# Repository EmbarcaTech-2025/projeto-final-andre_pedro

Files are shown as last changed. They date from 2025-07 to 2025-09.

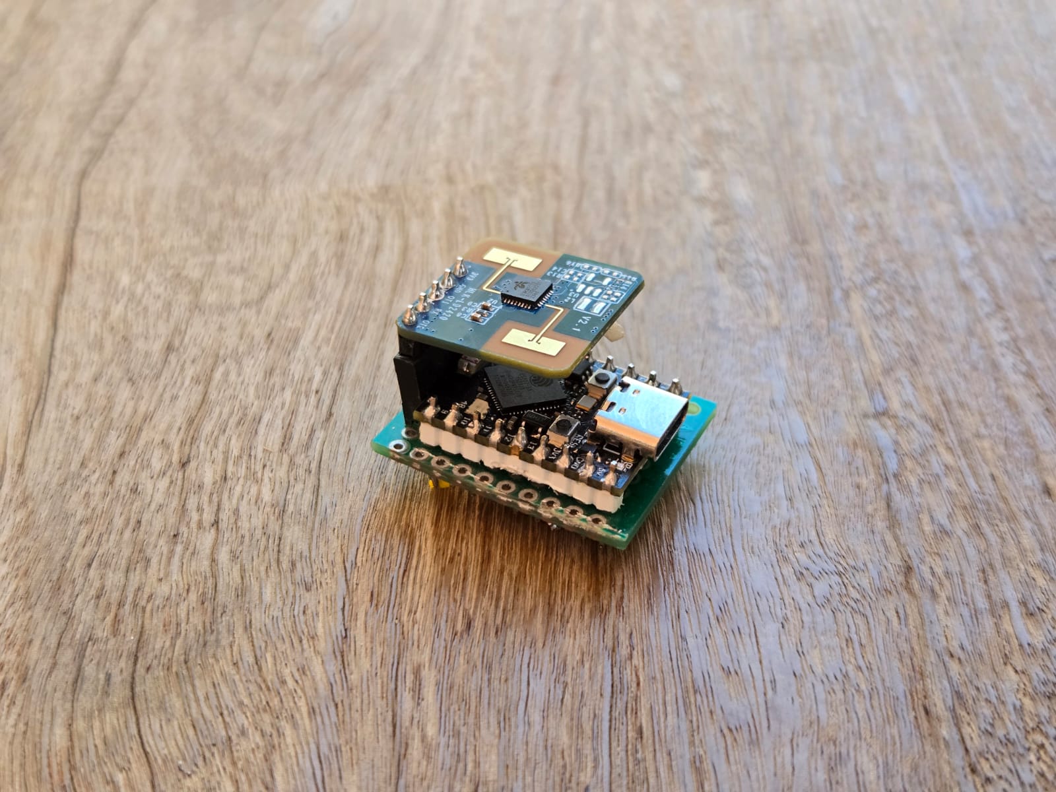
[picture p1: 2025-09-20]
etapa_4/imagens_e_videos/sonofree_mini_montagem.jpeg

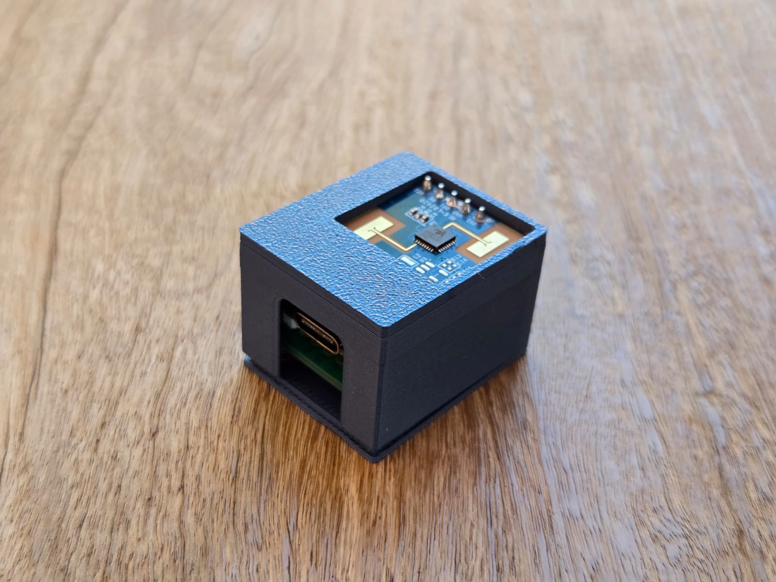
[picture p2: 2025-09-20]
etapa_4/imagens_e_videos/sonofree_mini_case.jpeg

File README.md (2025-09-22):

# SonoFree Mini

Sistema Inteligente de Detecção de Presença Humana com Sensor mmWave

## Sobre o Projeto

O SonoFree Mini é um interruptor inteligente que utiliza tecnologia mmWave (24GHz) para detecção precisa de presença humana. Diferentemente de sensores PIR convencionais, detecta pessoas completamente imóveis através de micromovimentos como respiração.

**Características principais:**
- Detecção de presença via sensor mmWave LD2420 (24GHz)
- Conectividade IoT via WiFi e MQTT
- Integração com Home Assistant
- Três modos de operação: Presença, Manual e Horário
- Encapsulamento compacto impresso em 3D

**Caminhos:**
- [Documentação](etapa_4/relatorio_tecnico.pdf)
- [Código fonte](etapa_4/codigo_esp32/sonofree.ino)
- [Modelo 3D](etapa_4/Part%Studio%1)
- [Lâmpada simulada (BitDogLab)](etapa_4/codigo_lampada_pico_w)
- [Imagens e vídeos](etapa_4/imagens_e_videos)
- [Apresetnção técnica](etapa_4/slides/sonofree_mini_tecnica.pdf)
- [Elevator pitch](etapa_4/slides/sonofree_mini_pitch.pdf)

## Arquitetura

```
Home Assistant ←→ MQTT ←→ ESP32 S3 ←→ LD2420 mmWave
                              ↓
                         Pico W ←→ LEDs WS2818B
```

### Componentes

- **ESP32 S3 SuperMini**: Microcontrolador principal, WiFi e MQTT
- **LD2420**: Sensor mmWave 24GHz para detecção de presença
- **Raspberry Pi Pico W**: Controle de LEDs (simulação de lâmpada)
- **LEDs WS2818B**: Array de 25 LEDs para indicação visual

## Instalação

### Hardware

**Conexões ESP32:**
```
ESP32 Pino 4  → LD2420 (UART)
ESP32 3V3     → LD2420 (VCC)
ESP32 GND     → LD2420 (GND)
```

**Conexões Pico W:**
```
Pico Pino 18  → Entrada digital
Pico Pino 7   → LEDs WS2818B (DIN)
```

### Software

**1. ESP32:**
- Edite credenciais WiFi e MQTT em `etapa_4/codigo_esp32/mmwave.ino`
- Compile e faça upload via Arduino IDE

**2. Pico W:**
```bash
cd etapa_4/codigo_lampada_pico_w
mkdir build && cd build
cmake ..
make
```

**3. Home Assistant:**
- Configure broker MQTT
- Adicione entidades via configuração MQTT

## Modos de Operação

### Modo Presença
Detecção automática via sensor mmWave. Liga ao detectar presença, desliga após timeout configurável (1-600 segundos).

### Modo Manual
Controle direto via interface Home Assistant. Switch ON/OFF simples.

### Modo Horário
Programação temporal com horários de início/fim configuráveis.

## Tópicos MQTT

- `home/sensor/cmd` - Mudança de modo
- `home/sensor/luz/cmd/presenca` - Controle luz modo presença
- `home/sensor/luz/cmd/manual` - Controle luz modo manual
- `home/sensor/luz/cmd/hora` - Controle luz modo horário
- `home/sensor/presenca/state` - Estado detecção presença
- `home/sensor/presenca/tempo_s/set` - Configuração timeout

## Calibração

O sensor LD2420 requer calibração prévia com software proprietário Windows:
1. Conecte sensor via UART TTL ao PC
2. Configure noise gates e threshold
3. Teste e salve configuração

## Limitações

### Hardware
- Relé não implementado (causa reinicializações na ESP32)
- Alimentação via USB-C necessária
- Calibração manual obrigatória

### Software
- Configuração WiFi hardcoded no código
- Dependência do Home Assistant para interface
- Comunicação ESP32-Pico W limitada a GPIO digital

## Especificações Técnicas

### ESP32 S3 SuperMini

### Sensor LD2420

### Encapsulamento
- Dimensões: 32,6mm × 27,6mm × 22mm
- Material: PLA (impressão 3D)

## Estrutura do Projeto

```
├── etapa_4/
│   ├── codigo_esp32/           # Firmware ESP32
│   ├── codigo_lampada_pico_w/  # Código Pico W
│   ├── slides/                 # Apresentações
│   └── videos/                 # Demonstrações
├── documentacao_tecnica.typ    # Documentação completa
└── README.md                   # Este arquivo
```

## Troubleshooting

**ESP32 não conecta WiFi:**
- Verifique credenciais no código
- Confirme alcance do sinal

**Sensor não detecta:**
- Verifique calibração do LD2420
- Confirme conexões GPIO 4

**MQTT desconectado:**
- Verifique broker ativo
- Confirme credenciais MQTT

## Equipe

**Desenvolvedores:**
- Andre Melo
- Pedro Rocha

**Projeto Final EmbarcaTech - 2025**

## Documentação

Para especificações técnicas detalhadas, consulte `documentacao_tecnica.typ`.

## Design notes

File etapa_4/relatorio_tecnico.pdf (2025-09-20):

Sistema inteligente de detecção de presença humana baseado em rede mesh

# Projeto Final

## Interruptor inteligente com detecção de presença hu mana com mmWave

## Sonofree Mini

### Andre de Oliveira Melo Pedro Sampaio

2025-09-19

## Introdução

O SonoFree Mini é um sistema inteligente de detecção de presença humana que utiliza tecnologia mmWave (ondas milimétricas) para criar interruptores mais inteligentes e eficientes. O projeto foi desenvolvido como trabalho final do programa EmbarcaTech, implementando uma solução IoT completa para automação residencial.
O sistema se diferencia de sensores convencionais por sua capacidade de detectar presença humana mesmo quando a pessoa está completamente imóvel, utilizando tecnologia de radar de 24GHz para identificar micromovimentos como respiração e batimentos cardíacos.

### Objetivos do Projeto

- Desenvolver um dispositivo que se integra facilmente a interruptores convencionais
- Implementar detecção de presença precisa utilizando tecnologia mmWave
- Criar conectividade IoT via WiFi e protocolo MQTT
- Fornecer interface de controle através de aplicação web/mobile
- Demonstrar integração com sistemas de automação residencial (Home Assistant)

### Motivação

Sistemas tradicionais de detecção de presença baseados em PIR (Passive Infrared) apresentam limitações significativas, especialmente na detecção de pessoas estáticas. O SonoFree Mini resolve essa limitação utilizando tecnologia mmWave, oferecendo:
- Detecção através de materiais (não necessita linha de visão direta)
- Capacidade de detectar pessoas completamente imóveis
- Maior precisão espacial e temporal
- Operação “invisível” ao usuário final

## Tecnologia mmWave

### Princípios de Funcionamento

A tecnologia mmWave (millimeter wave) utiliza ondas eletromagnéticas na faixa de 24GHz para detecção de presença e movimento. O funcionamento baseia-se nos seguintes princípios:

Detecção de Distância
O sensor transmite um chirp (sinal que aumenta linearmente em frequência ao longo do tempo). Quando este sinal atinge um objeto, ele é refletido de volta para o sensor. O sistema:
1. Combina os sinais transmitidos e recebidos
2. Gera uma Frequência Intermediária (IF)
3. Calcula a distância baseada na fórmula: IF = (Slope × 2 × Distância) / c Onde:
- Slope: taxa de variação da frequência do chirp
- c: velocidade da luz
- IF: frequência intermediária resultante

Detecção de Movimento e Presença
Para detectar movimento, o sensor:
1. Transmite múltiplos chirps separados no tempo
2. Analisa mudanças de fase entre os chirps

3. Utiliza RangeFFT para determinar distância
4. Aplica DopplerFFT para detecção de velocidade
A capacidade de detectar micromovimentos permite identificar pessoas estáticas através da respiração e outros movimentos corporais mínimos.

### Vantagens da Tecnologia mmWave

- Detecção através de superfícies: Funciona mesmo com obstáculos físicos
- Alta precisão: Detecta movimentos na ordem de milímetros
- Operação ubíqua: Não emite luz visível ou sons audíveis
- Eficiência espacial: Melhor resolução espacial que sensores PIR
- Detecção de pessoas estáticas: Principal diferencial da tecnologia

## Arquitetura do Sistema

### Visão Geral

O SonoFree Mini implementa uma arquitetura IoT distribuída composta pelos seguintes elementos:

Home Assistant ←→ MQTT Broker ←→ ESP32 S3 SuperMini ←→ Sensor LD2420
↓
Raspberry Pi Pico W ←→ LEDs WS2818B

### Componentes Principais

ESP32 S3 SuperMini
- Função: Microcontrolador principal do sistema
- Responsabilidades:
- Comunicação WiFi
- Cliente MQTT
- Processamento de sinais do sensor mmWave
- Gerenciamento dos modos de operação
- Interface com sistema de automação

Sensor LD2420 mmWave
- Frequência de operação: 24GHz
- Interface de comunicação: UART e GPIO
- Alimentação: 3.3V
- Faixa de detecção: Configurável via software proprietário
- Características especiais:
- Noise gates configuráveis
- Threshold ajustável
- Detecção de micromovimentos

Raspberry Pi Pico W (Simulação de Carga)
- Função: Simulação de lâmpada inteligente
- Componentes controlados: 25 LEDs WS2818B
- Interface: GPIO digital (pino 18)
- Implementação: PIO (Programmable I/O) para timing preciso

### Comunicação e Protocolos

MQTT Topics
O sistema utiliza os seguintes tópicos MQTT para comunicação:
- home/sensor/cmd: Controle de modo de operação
- home/sensor/luz/cmd/presenca: Controle de luz no modo presença
- home/sensor/luz/cmd/manual: Controle de luz no modo manual
- home/sensor/luz/cmd/hora: Controle de luz no modo horário
- home/sensor/presenca/state: Estado de detecção de presença
- home/sensor/presenca/tempo_s/set: Configuração de temporizador
- home/sensor/presenca/tempo_s/state: Estado do temporizador

WiFi e Conectividade
- Padrão: 802.11 b/g/n
- Reconexão automática em caso de perda de sinal
- Configuração via código fonte (SSID e senha)

## Implementação de Hardware

### Especificações de Alimentação

Sistema de Alimentação:
- Fonte: USB-C via ESP32 S3 SuperMini
- Tensão do sistema: 5V (USB) / 3.3V (lógica)
- Alimentação do sensor: 3.3V derivado da ESP32
- Consumo estimado: < 500mA

### Conexões Físicas

ESP32 S3 SuperMini

Pino 4 | → LD2420 (Sinal UART)
3V3 | → LD2420 (VCC)
GND | → LD2420 (GND)
Pino 1 | → Saída para relé (não implementado)
Raspberry Pi Pico W

Pino 18 → Entrada digital (sinal de presença)
Pino 7 | → Saída para LEDs WS2818B
3V3 | → Alimentação LEDs
GND | → Terra comum

### Limitações de Hardware Identificadas

Relé não implementado: Durante os testes, identificou-se que o uso de relé causava reinicializações na ESP32, provavelmente devido a:
- Picos de corrente durante acionamento
- Interferência eletromagnética
- Insuficiência de alimentação
Solução adotada: Implementação de simulação via LEDs WS2818B controlados pelo Pico W.

### Encapsulamento

Dimensões físicas: 32,6mm × 27,6mm × 22mm Material: PLA (impressão 3D) Características do encapsulamento:
- Proteção dos componentes eletrônicos
- Acesso para conexão USB-C
- Aberturas para propagação do sinal mmWave
- Design compacto para instalação em caixas de interruptor
Nota sobre experiência: Este foi o primeiro projeto de impressão 3D para ambos os membros da equipe, representando um aprendizado adicional em prototipagem física.

## Implementação de Software

### ESP32 Firmware Principal

Estrutura do Código
O firmware da ESP32 implementa uma máquina de estados com três modos principais de operação:

enum Modo { MODO_PRESENCA, MODO_MANUAL, MODO_HORA };
Modo Presença
No modo presença, o sistema opera com as seguintes características:
Debounce e Qualificação:
- Debounce hardware: 5ms
- Qualificação de sinal: 50ms
- Prevenção contra falsos positivos
Algoritmo de Detecção:
1. Borda de subida: Inicia qualificação de 50ms
2. Manutenção do sinal alto: Confirma presença
3. Borda de descida: Inicia contagem de timeout
4. Timeout configurável: Desliga após período sem presença Parâmetros Configuráveis:
- Tempo ativo: 1 a 600 segundos (padrão: 10s)
- Persistência em memória não-volátil
- Configuração via MQTT

Comunicação MQTT
Características da implementação:
- Buffer de 256 bytes
- Reconnexão automática
- Mensagens com retenção
- Cliente ID único baseado em hardware Tratamento de Comandos:
- Parsing robusto de payloads JSON
- Validação de comandos

- Feedback via tópicos de estado

Gestão de Energia e Conectividade WiFi:
- Modo Station (STA)
- Timeout de conexão: 60 segundos
- Reinicialização automática em caso de falha Watchdog:
- Monitoramento contínuo de conectividade
- Recovery automático de falhas de rede

### Raspberry Pi Pico W Controle de LEDs

Implementação PIO
O controle dos LEDs WS2818B utiliza o sistema PIO (Programmable I/O) do RP2040:

.program ws2818b
.side_set 1
.wrap_target
out x, 1 | side 0 [2]
jmp !x, 3 | side 1 [1]
jmp 0 | side 1 [4]
nop | side 0 [4]
.wrap
Características técnicas:
- Frequência de operação: 800kHz
- Protocolo WS2818B nativo
- Timing preciso via hardware
- 25 LEDs em configuração matricial

Processamento de Entrada
Debounce implementado:
- Duas leituras com intervalo de 10ms
- Validação por consenso
- Atualização apenas em mudanças de estado Loop principal:
- Polling a cada 5ms
- Resposta imediata a mudanças
- Controle de cor sólida (branco/apagado)

## Interface de Usuário

### Home Assistant Integração

O sistema integra-se ao Home Assistant através do addon MQTT, criando as seguintes entidades:

Modo Presença
Interface para controle automático baseado em detecção:
- Status de presença em tempo real
- Configuração de tempo ativo
- Histórico de detecções

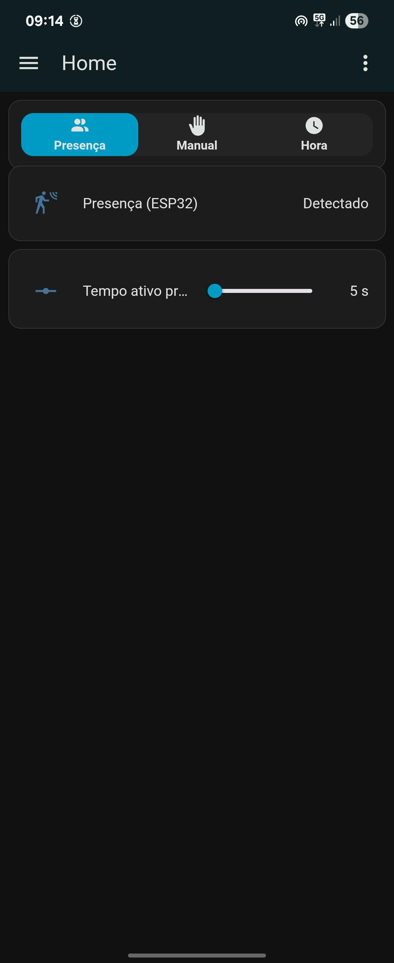
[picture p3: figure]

Modo Manual
Controle direto pelo usuário:
- Switch ON/OFF simples
- Override manual da detecção automática
- Status de conexão do dispositivo

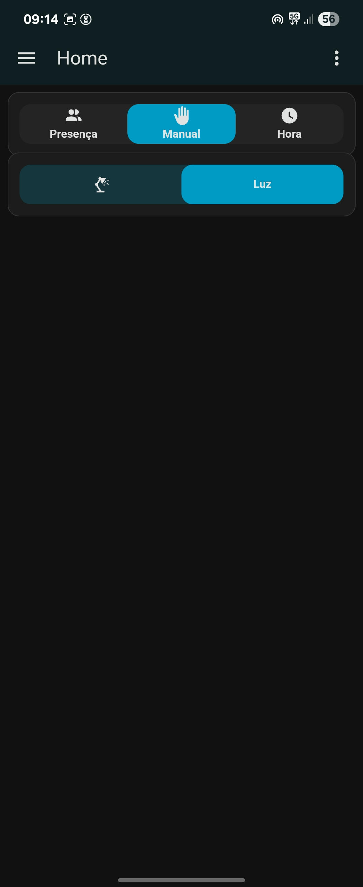
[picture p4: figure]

Modo Horário
Programação temporal:
- Configuração de horários de início/fim
- Programação semanal
- Integração com automações

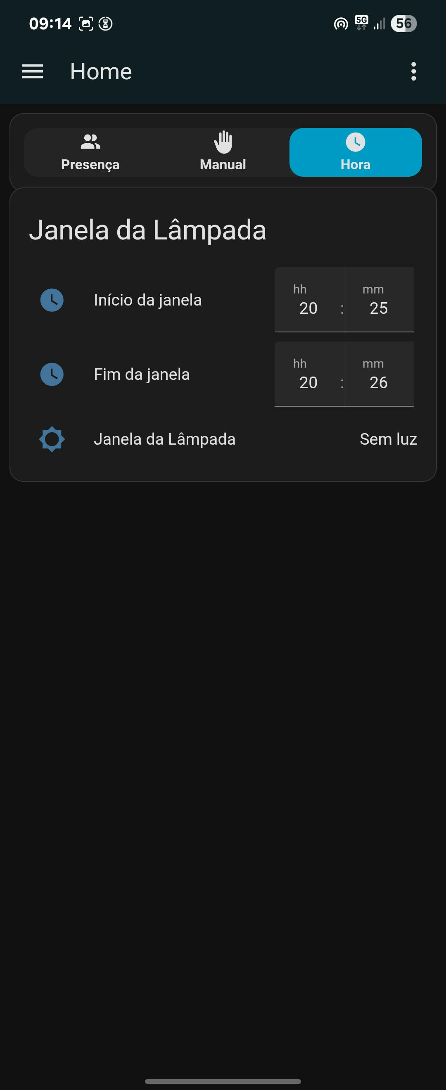
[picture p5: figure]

### Aplicação Mobile/Web

O sistema é acessível através da interface web do Home Assistant, proporcionando:
- Controle remoto via internet
- Notificações push
- Integração com outros dispositivos IoT
- Dashboards personalizáveis

## Calibração e Configuração

### Sensor LD2420

Software de calibração:
- Aplicação proprietária (Windows only)
- Comunicação via UART TTL
- Interface gráfica para ajustes Parâmetros configuráveis:
- Noise gates: Filtros de ruído ambiental
- Threshold: Sensibilidade de detecção
- Zonas de detecção: Áreas específicas de monitoramento Processo de calibração:
1. Conexão direta UART com o sensor
2. Mapeamento do ambiente
3. Ajuste de sensibilidade
4. Teste de falsos positivos/negativos
5. Salvamento de configuração no sensor

### Sistema MQTT

Configuração de broker:
- Servidor local ou na nuvem
- Autenticação por usuário/senha
- QoS configurável por tópico
Descoberta automática:
- Integration via Home Assistant MQTT Discovery
- Criação automática de entidades
- Configuração zero para usuário final

## Desafios e Limitações

### Desafios Técnicos Enfrentados

Rede Mesh
Desafio original: Implementação de comunicação mesh entre múltiplos dispositivos. Limitação encontrada: Complexidade de implementação e debugging em prazo limitado. Solução adotada: Migração para arquitetura WiFi + MQTT, mais robusta e bem documentada.

Interferência Eletromagnética
Problema: Reinicializações da ESP32 ao acionar relé.

Causa provável: Picos de corrente e EMI do relé.
Solução: Simulação via LEDs WS2818B no Pico W.

Calibração do Sensor
Desafio: Dependência de software proprietário Windows para calibração. Limitação: Impossibilidade de calibração automática via firmware. Impacto: Necessidade de calibração manual prévia à instalação.

### Limitações Atuais

Hardware
- Ausência de relé para controle direto de cargas AC
- Dependência de alimentação USB
- Sensor não configurável via firmware

Software
- Configuração WiFi hardcoded
- Ausência de interface web própria para configuração
- Dependência de Home Assistant para interface gráfica

Integração
- Protocolo de comunicação ESP32 ↔ Pico W limitado a GPIO digital
- Ausência de feedback de status do Pico W

## Melhorias Futuras

### Propostas de Evolução

Hardware
- Implementação de fonte chaveada 12V/3.3V
- Relé de estado sólido para controle AC
- PCB customizada para redução de tamanho
- Proteções contra surtos e EMI

Software
- Interface web embarcada para configuração
- Protocolo de comunicação bidirecional via UART/I2C
- OTA (Over-The-Air) updates
- Configuração WiFi via portal captivo

Funcionalidades
- Múltiplas zonas de detecção
- Aprendizado de padrões de ocupação
- Integração com outros sensores (temperatura, umidade, luminosidade)
- API REST para integração com outros sistemas

Conectividade
- Implementação de rede mesh (ESP-NOW ou Thread)
- Suporte a múltiplos protocolos (Zigbee, Matter)

- Modo offline com sincronização posterior

## Resultados e Conclusões

### Funcionalidades Implementadas

O projeto SonoFree Mini alcançou os seguintes objetivos:
✓ Detecção de presença mmWave: Implementação bem-sucedida com sensor LD2420 ✓ Conectividade IoT: Comunicação estável via WiFi e MQTT
✓ Múltiplos modos de operação: Presença, Manual e Horário funcionais
✓ Interface gráfica: Integração completa com Home Assistant
✓ Encapsulamento físico: Protótipo funcional em PLA

### Aprendizados

Tecnologia mmWave: Compreensão profunda dos princípios de radar e processamento de sinais. Sistemas embarcados: Experiência prática com ESP32 e Raspberry Pi Pico W.
Protocolos IoT: Implementação robusta de comunicação MQTT.
Prototipagem: Primeira experiência com impressão 3D e design mecânico.
Integração de sistemas: Orquestração de múltiplos componentes em solução única.

### Impacto e Aplicabilidade

O SonoFree Mini demonstra viabilidade técnica e comercial como solução de automação residencial. As principais contribuições incluem:
- Prova de conceito de detecção mmWave em ambientes residenciais
- Arquitetura escalável para múltiplos dispositivos
- Base sólida para desenvolvimento de produto comercial
- Documentação técnica completa para replicação

### Considerações Finais

O projeto SonoFree Mini representa um marco importante no desenvolvimento de soluções IoT aces-síveis e eficientes. Apesar das limitações identificadas, a implementação atual fornece uma base sólida para evolução futura.
A experiência adquirida durante o desenvolvimento, especialmente na integração de tecnologias mmWave com sistemas embarcados convencionais, contribui significativamente para o estado da arte em automação residencial no contexto brasileiro.
As melhorias propostas indicam um caminho claro para transformação do protótipo atual em produto comercialmente viável, atendendo às demandas crescentes por soluções de casa inteligente no mercado nacional.

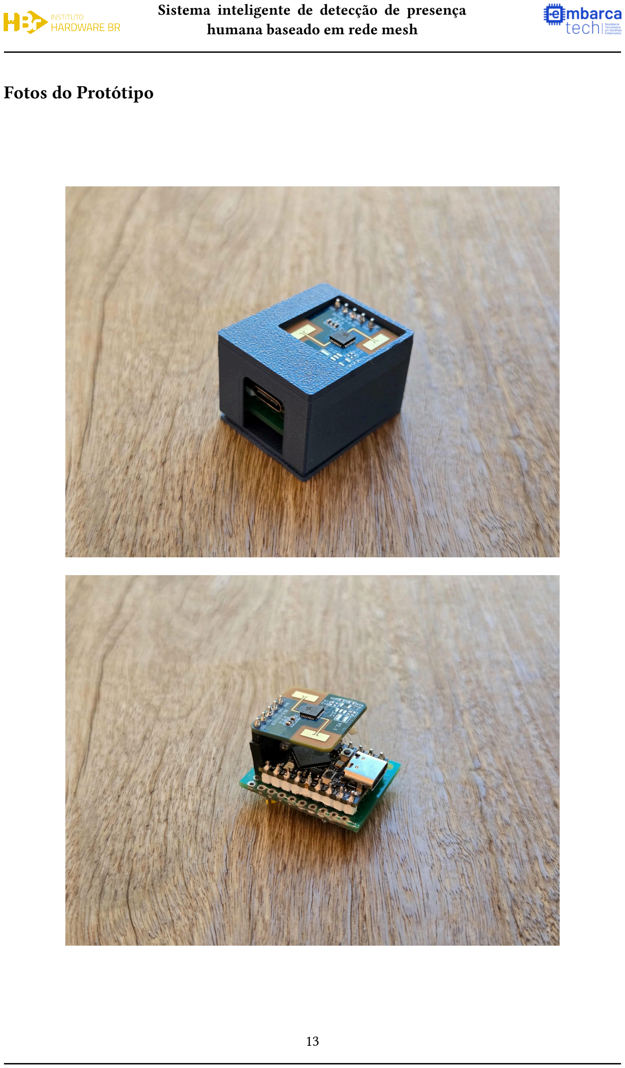
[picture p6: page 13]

### Fotos do Protótipo

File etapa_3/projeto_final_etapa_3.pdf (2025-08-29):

Sistema inteligente de detecção de presença hu mana baseado em rede mesh

# Projeto Final - Etapa 2

### Sistema inteligente de detecção de presença humana baseado em rede mesh

Experimento, Desafios e Melhorias

Andre de Oliveira Melo
Pedro Sampaio

20250829

Montagem do Sistema

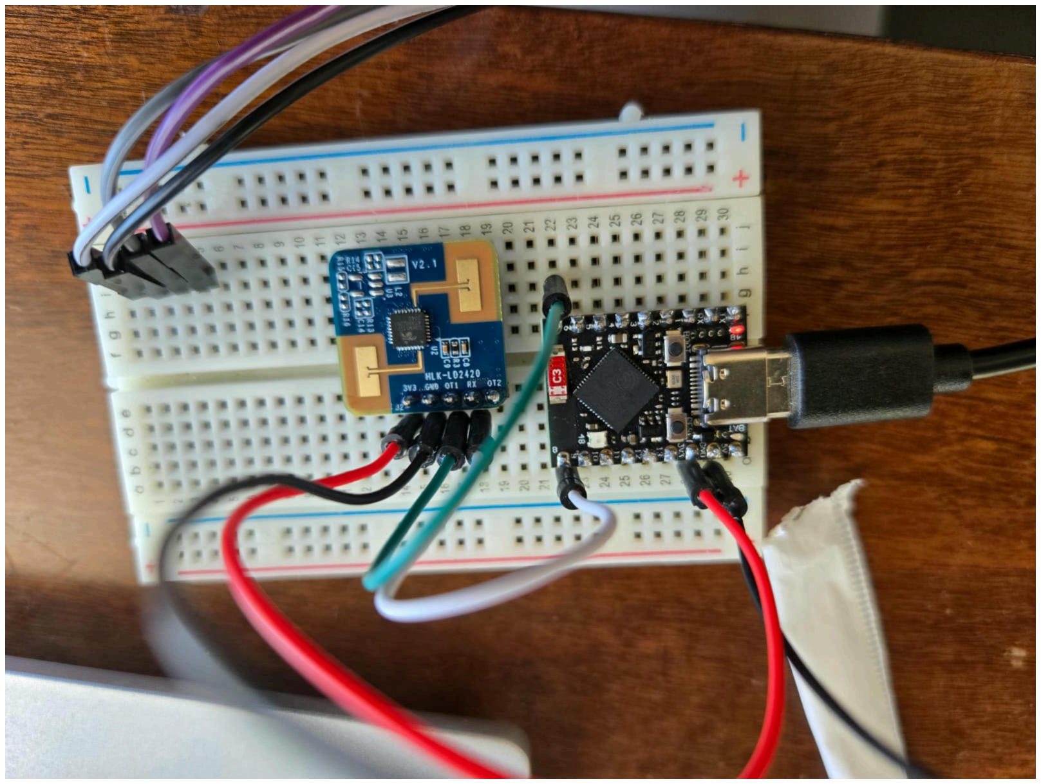
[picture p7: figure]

Descrição, Explicação e Testes

O vídeo de teste, disponível no YouTube, demonstra o procedimento de apro ximação e afastamento em relação ao sensor, acompanhado de uma breve explicação. Ele pode ser acessado por meio deste link. (https://youtube.com/shorts/Sf1ZEruXKiU?feature=share)
No registro, é apresentado o funcionamento do sensor mmWave HLKLD2420, conectado a uma placa ESP32S3 Super Mini. Os dados coletados são transmitidos via WiFi para uma interface executada em um notebook, permitindo a visuali zação em tempo real da distância entre o narrador e o sensor.

Desafios Identificados

Durante o desenvolvimento do sistema, diferentes desafios técnicos foram observados em etapas distintas da implementação. Inicialmente, a montagem do hardware apresentou dificuldades devido a inconsistências no datasheet do sensor, que fornecia informações incorretas sobre os pinos de transmissão (TX)

e recepção (RX) da UART, embora o pinout estivesse configurado corretamente no projeto.
Na sequência, surgiram obstáculos relacionados ao uso do barramento UART conectado ao conector USB da ESP32 Super Mini, que exigia ajustes específicos de configuração não previamente conhecidos pela equipe.
Após a resolução dessas etapas, a implementação do código responsável pela requisição e interpretação dos dados do sensor também apresentou complexi dade. Embora fosse possível verificar a atualização dos dados recebidos, a correta interpretação exigiu refinamento do processo de parsing.

Resumo dos desafios identificados

- Inconsistências no datasheet do sensor (pinos TX e RX da UART).
- Necessidade de configuração específica do barramento UART conectado ao USB da ESP32 Super Mini.
- Dificuldades no desenvolvimento do código para requisição e parsing dos dados do sensor.

Melhorias Propostas

As melhorias propostas têm como finalidade alinhar as funcionalidades do sistema aos requisitos estabelecidos na Entrega 1 do trabalho final. As principais direções de aprimoramento técnico são:
- Calibração do sensor via UART: permitirá maior precisão nas medições de distância, reduzindo erros e minimizando a ocorrência de falsos positivos na detecção de micromovimentos.
- Implementação da detecção de micromovimentos: funcionalidade destinada a identificar a presença humana mesmo em situações de baixa ou nenhuma movimentação visível.
- Interface web integrada ao firmware: disponibilizará recursos de configuração de tempo, definição de zonas de iluminação, seleção entre modos de controle manual e automático, além de garantir suporte no firmware para interpretar e executar tais comandos.

- Rede mesh entre múltiplos dispositivos: possibilitará escalabilidade e comu nicação distribuída, permitindo a cooperação entre diferentes unidades do sistema.
- Integração de interruptor e relé para acionamento de lâmpada: permitirá validar o sistema em um cenário real de automação, controlando a iluminação tanto de forma manual quanto automática.
- Registro de LOG em cartão SD (baixa prioridade): será implementada a funci onalidade de armazenamento local, possibilitando análise posterior dos dados coletados.
- Monitoramento ambiental e integração com plataformas IoT (baixa priori dade): expansão das capacidades do sistema por meio da coleta de parâmetros ambientais e comunicação com aplicações de Internet das Coisas.
- Desenvolvimento de case para o sensor e o microcontrolador (baixa priori dade): visa garantir maior robustez física, proteção contra danos externos e melhor organização do protótipo.

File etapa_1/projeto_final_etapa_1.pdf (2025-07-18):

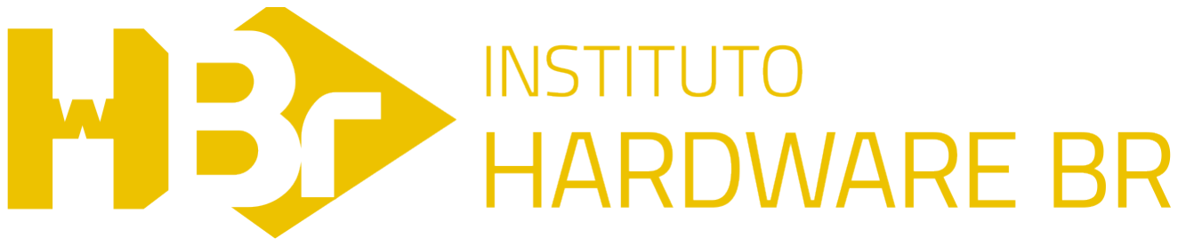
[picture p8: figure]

# Projeto Final - Etapa 2

## Sistema inteligênte de detecção de presença humana baseado em rede mesh

### Andre de Oliveira Melo Pedro Sampaio

18 de julho de 2025

Sistema inteligênte de detecção de presença humana baseado em rede mesh

## 1 Identificação do Problema

### 1.1 Contextualização

O controle e a otimização do consumo de energia em ambientes residenciais e comerciais representam, atualmente, uma área com significativo potencial de ganhos financeiros e ambientais. Historicamente, o uso de sistemas manuais para o acionamento de dispositivos elétricos e de iluminação tem levado a um desperdício energético considerável. Isso ocorre porque, muitas vezes, aparelhos e luzes permanecem ligados por longos períodos, mesmo quando os espaços estão desocupados.
Em um cenário em que a eficiência energética é uma prioridade, superar essas ineficiências torna-se crucial. É nesse contexto que os detectores de presença humana, baseados em tecnologias distribuídas, surgem como uma solução robusta e altamente eficiente para a economia de energia. Ao utilizar uma rede distribuída, tendo a topologia mesh como referência, cada detector atua não apenas como um ponto de detecção, mas também como um repetidor de sinal, ampliando a área de sensoriamento. Isso permite uma cobertura abrangente e estável em grandes áreas ou em ambientes com obstáculos, garantindo que a detecção de presença seja precisa. Com essa capacidade, o sistema pode desligar ou ajustar automaticamente o funcionamento de luzes, aparelhos de ar-condicionado, ventilação e outros dispositivos quando não há ninguém presente, e ativá-los instantaneamente ao detectar presença.

### 1.2 Problema Principal

O controle ineficiente de iluminação e dispositivos elétricos em ambientes residenciais e comerciais representa um problema significativo. Atualmente, a dependência da ação manual do usuário, por meio de interruptores tradicionais, leva a um consumo excessivo de energia, como luzes acesas em ambientes desocupados. Além disso, tecnologias existentes, como os sensores infravermelho passivo (PIR), demonstram limitações de precisão e cobertura em espaços amplos, resultando em detecções falhas ou desnecessárias que comprometem a economia de energia esperada. Esses fatores evidenciam a necessidade urgente de soluções mais avançadas para a otimização do uso de recursos.
O alto consumo de energia derivado dessa ineficiência não se restringe apenas ao impacto financeiro nas contas de luz. Ele se traduz diretamente em consequências ambientais significativas, contribuindo para o aumento da demanda por geração de energia, que muitas vezes ainda depende de fontes não renováveis e poluentes. Esse cenário agrava a emissão de gases de efeito estufa, o esgotamento de recursos naturais e a sobrecarga de infraestruturas, evidenciando a urgência de soluções que promovam um uso mais consciente e sustentável da energia.

### 1.3 Limitações dos Sistemas Atuais

Os sistemas de detecção de presença tradicionais, como sensores PIR (Passive Infrared), apresentam limitações significativas:

- Sensibilidade limitada a movimentos, não detectando pessoas estáticas
- Maior consumo de espaço físico
- Alcance de detecção restrito presença humana baseado em rede mesh
- Dificuldade de integração com múltiplos dispositivos
- Ausência de comunicação entre sensores em ambientes amplos
- Não detecção através de barreiras físicas

## 2 Proposta de Solução

### 2.1 Descrição Geral

O projeto propõe o desenvolvimento de um sistema inteligente de detecção humana que emprega a tecnologia mmWave (ondas milimétricas), utilizando o sensor LD2420. Este sistema visa oferecer a capacidade de detectar a presença humana com alta precisão, permitindo o controle automatizado de iluminação e outros dispositivos elétricos. Adicionalmente, o sistema permitirá a operação coordenada entre múltiplos sensores em um mesmo ambiente, visando uma cobertura eficiente e robusta.

### 2.2 Tecnologia mmWave

A tecnologia mmWave usa ondas eletromagnéticas nas faixas de 24GHz ou 60GHz para identificar a presença e o movimento. Essa abordagem oferece vantagens notáveis quando comparada aos sensores PIR convencionais. Por exemplo, ela consegue detectar através de certos obstáculos, possui um tamanho físico reduzido e, crucialmente, é capaz de identificar pessoas que estão estáticas, algo que os sensores PIR muitas vezes não conseguem fazer.

### 2.3 Funcionalidades Principais

- Detecção automática de presença humana mesmo estático
- Controle de baseado em presença
- Controle de dispositivos auxiliares (ar condicionado, tomadas inteligentes)
- Comunicação entre múltiplos sensores
- Manutenção coordenada de zonas de iluminação

## 3 Requisitos do Sistema

### 3.1 Requisitos Funcionais

1. RF02 - Controle de Iluminação: O sistema deve ligar e desligar automaticamente a iluminação e dispositivos auxiliares com base na detecção de presença.
2. RF03 - Comunicação Múltipla: O sistema deve permitir comunicação wireless entre sensores para operação coordenada.
3. RF04 - Coordenação de Zonas: O sistema deve manter iluminação e dispositivos ativos em zonas cobertas por sensores coordenados.

presença humana baseado em rede mesh

4. RF05 - Configuração de Tempo: O sistema deve permitir configuração do tempo de desligamento automático dos dispositivos.
5. RF06 - Interface de Usuário: O sistema deve fornecer interface visual local via display e-Paper e interface remota via aplicação mobile.
6. RF07 - Controle Manual: O sistema deve permitir acionamento manual de iluminação e dispositivos por meio de botões físicos, sem comprometer a lógica automática.
7. RF08 - Monitoramento de Ambiente: O sistema deve ser capaz de medir temperatura e umidade do ambiente por meio de sensores apropriados.
8. RF09 - Mensuração de Luminosidade: O sistema deve medir o nível de luminosidade do ambiente com base em sensores de luz.
9. RF10 - Registro de Dados: O sistema deve registrar, em tempo real, os dados de presença, temperatura, umidade e luminosidade em um cartão SD.
10. RF11 - Visualização Remota: O sistema deve disponibilizar os dados registrados para visualização em uma interface mobile.
11. RF12 - Integração com Aplicativos IoT: O sistema deve ser compatível com plataformas de IoT (como Blynk, Home Assistant ou similares) para visualização e controle remoto dos sensores e atuadores.

### 3.2 Requisitos Não Funcionais

1. RNF01 - Eficiência Energética: O sistema deve atingir eficiência energética melhor do que a de um sistema tradicional utilizando sensor PIR
2. RNF02 - Tempo de Resposta: O sistema deve responder à detecção de presença em menos de 2 segundos
3. RNF03 - Temperatura de Operação: O sistema deve operar em temperaturas normais
4. RNF04 - Conectividade: O sistema deve ser controlável via aplicação mobile
5. RNF05 - Tamanho: O sistema deve poder ser contido (sob hardware customizável) em um interruptor convencional

## 4 Lista de Materiais

### 4.1 Componentes Principais

A Tabela 1 apresenta os principais componentes utilizados na implementação do sistema proposto. Os elementos listados foram selecionados com base em suas funcionalidades específicas, como detecção de presença, medição ambiental e interface com o usuário. Além disso, os componentes de comunicação e armazenamento, como o módulo SD e os periféricos I2C/SPI, garantem a integração eficiente e a flexibilidade necessária para o funcionamento do sistema distribuído baseado em rede mesh.

presença humana baseado em rede mesh

Componente | Especificação | Qtd
Raspberry Pi Pico W | Microcontrolador RP2040 (BitDogLab) | 2
Sensor LD2420 | Sensor mmWave 24GHz - UART | 2
Display epaper | Resolução 122x250 - SPI | 2
AHT10 | Sensor de temperatura e humidade - i2c | 2
Módulo cartão SD | Periférico de SDCARD - SPI | 2
BH1750 | Sensor de luminosidade - i2c | 2
Extensor i2c | Periférico de extensão i2c | 2

Tabela 1: Lista de componentes principais.

### 4.2 Componentes Auxiliares

A Tabela 2 apresenta os componentes auxiliares utilizados na montagem e finalização do protótipo, essenciais para garantir a fixação, organização e funcionalidade física do sistema.

Componente | Descrição | Quantidade
Cartão SD | Cartão SD para log | 2
Jumpers | Fios de conexão | 20
Caixa do detector | Case para o projeto | 2
Parafusos | Parafusos de fixação M3 | 8
Fita Dupla Face | Fixação de componentes | 1

Tabela 2: Componentes auxiliares.

## 5 Justificativa Técnica

### 5.1 Vantagens da Tecnologia mmWave

A escolha da tecnologia mmWave para este projeto se baseia em várias vantagens técnicas significativas em relação aos sensores PIR tradicionais:
Detecção Aprimorada: O sensor LD2420 utiliza ondas milimétricas de 24GHz que permitem detecção através de materiais não metálicos, incluindo vidro, plástico e tecido. Esta característica elimina a necessidade de linha de visão direta, comum em sensores PIR. Além disso, eles também são capazes de detectar pessoas que não estão em movimento.
Precisão de Movimento: A tecnologia mmWave pode detectar movimentos sutis, incluindo respiração e movimentos mínimos, permitindo identificação de presença mesmo quando a pessoa está relativamente estática.
Eficiência Espacial: O tamanho reduzido dos componentes mmWave permite integração em espaços mais compactos, facilitando instalação em diferentes tipos de ambientes.

### 5.2 Vantagens da solução proposta

A ideia é oferecer uma solução integrada, versátil e de fácil uso.
Eficiência Espacial: Com o tamanho dos componentes utilizados, é possível ter os componentes todos atrás de um interruptor convencional adaptado.

presença humana baseado em rede mesh

Facilidade de uso e comforto: O objetivo é que seja facilmente utilizado por qualquer pessoa. A inclusão de um software de fácil uso, integração entre mais de um sensor e possibilidade de detectar usuários imóveis promovem uma melhor experiência ao usuário. Além disso, a possibilidade de integrar outros dispositivos além de lâmpadas acrescenta conveniência.
Eficiência Energética: A possibilidade de controlar não só iluminação com base em presença, como também outros dispositivos IoT promove uma eficiência energética ainda maior.

## Referências

[1] TEXAS INSTRUMENTS. mmWave Radar Academy. 2024. Disponível em: https:
//dev.ti.com/tirex/explore/node?node=A__AXNV8Pc8F7j2TwsB7QnTDw__RADAR-ACADEMY_ _GwxShWe__LATEST. (https://dev.ti.com/tirex/explore/node?node=A__AXNV8Pc8F7j2TwsB7QnTDw__RADAR-ACADEMY__GwxShWe__LATEST) Acesso em: 16 jul. 2025.

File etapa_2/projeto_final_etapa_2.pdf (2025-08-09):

Sistema inteligente de detecção de presença humana baseado em rede mesh

# Projeto Final - Etapa 2

## Sistema inteligente de detecção de presença humana baseado em rede mesh

## Arquitetura e Modelagem

### Andre de Oliveira Melo Pedro Sampaio

2025-08-08

## Diagrama de Hardware

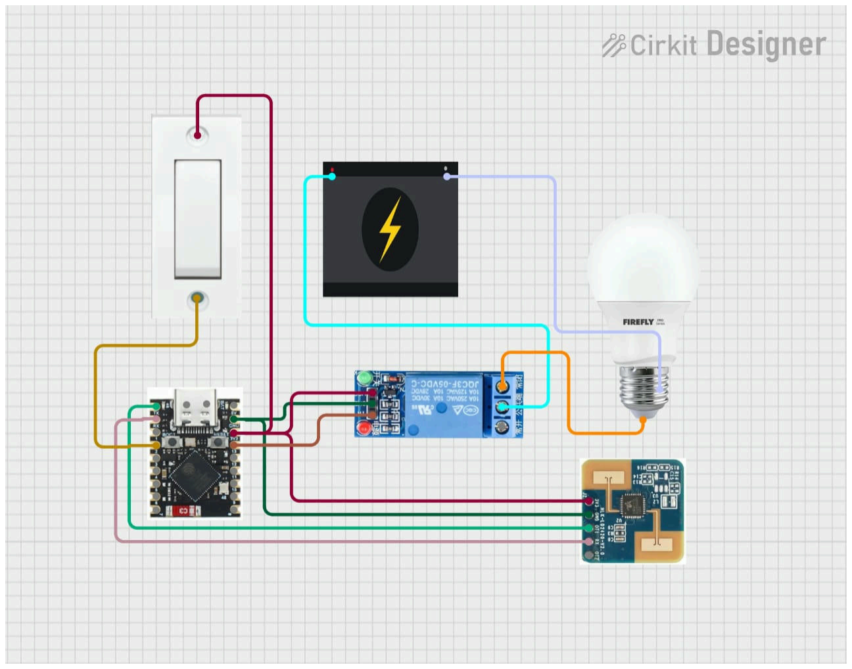
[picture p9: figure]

## Blocos Funcionais

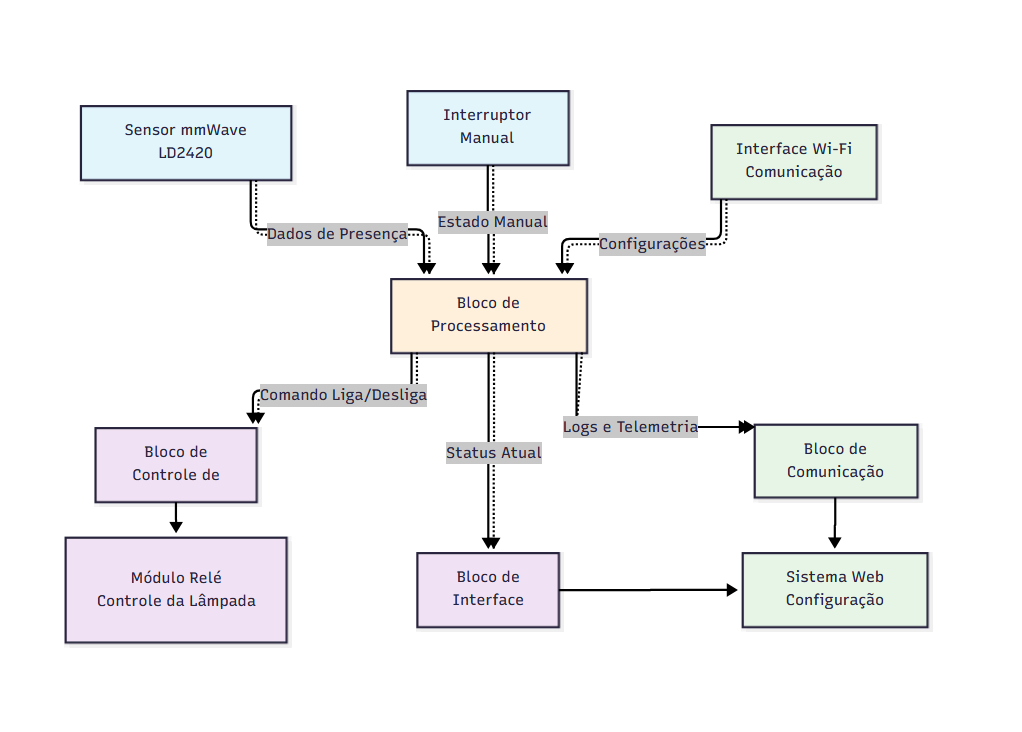
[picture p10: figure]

## Fluxograma do Software

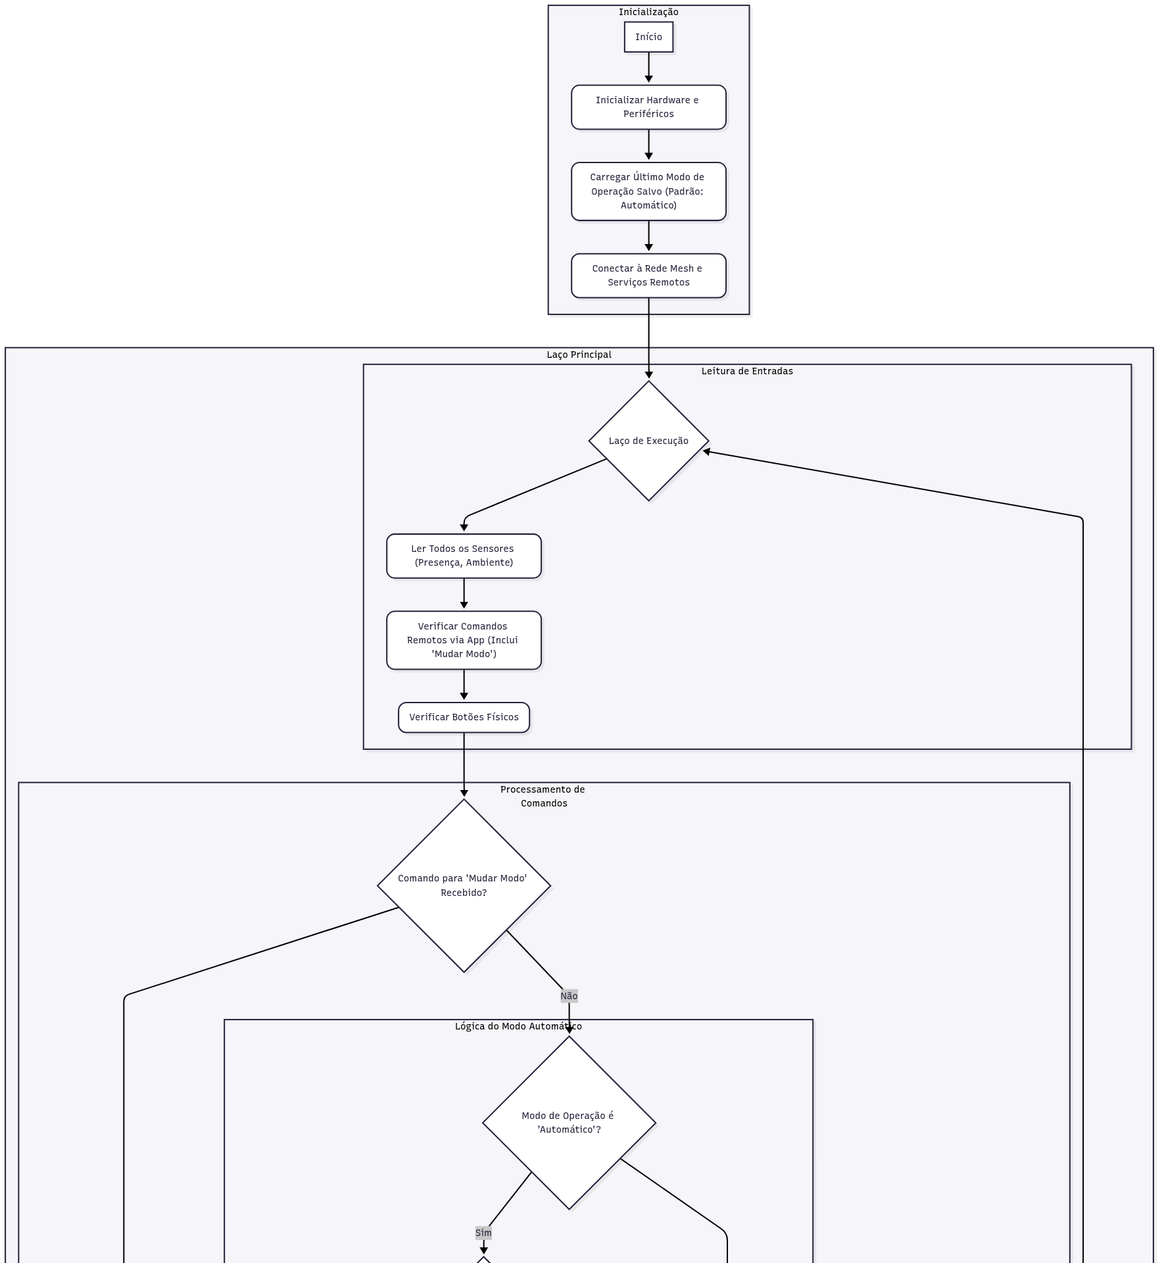
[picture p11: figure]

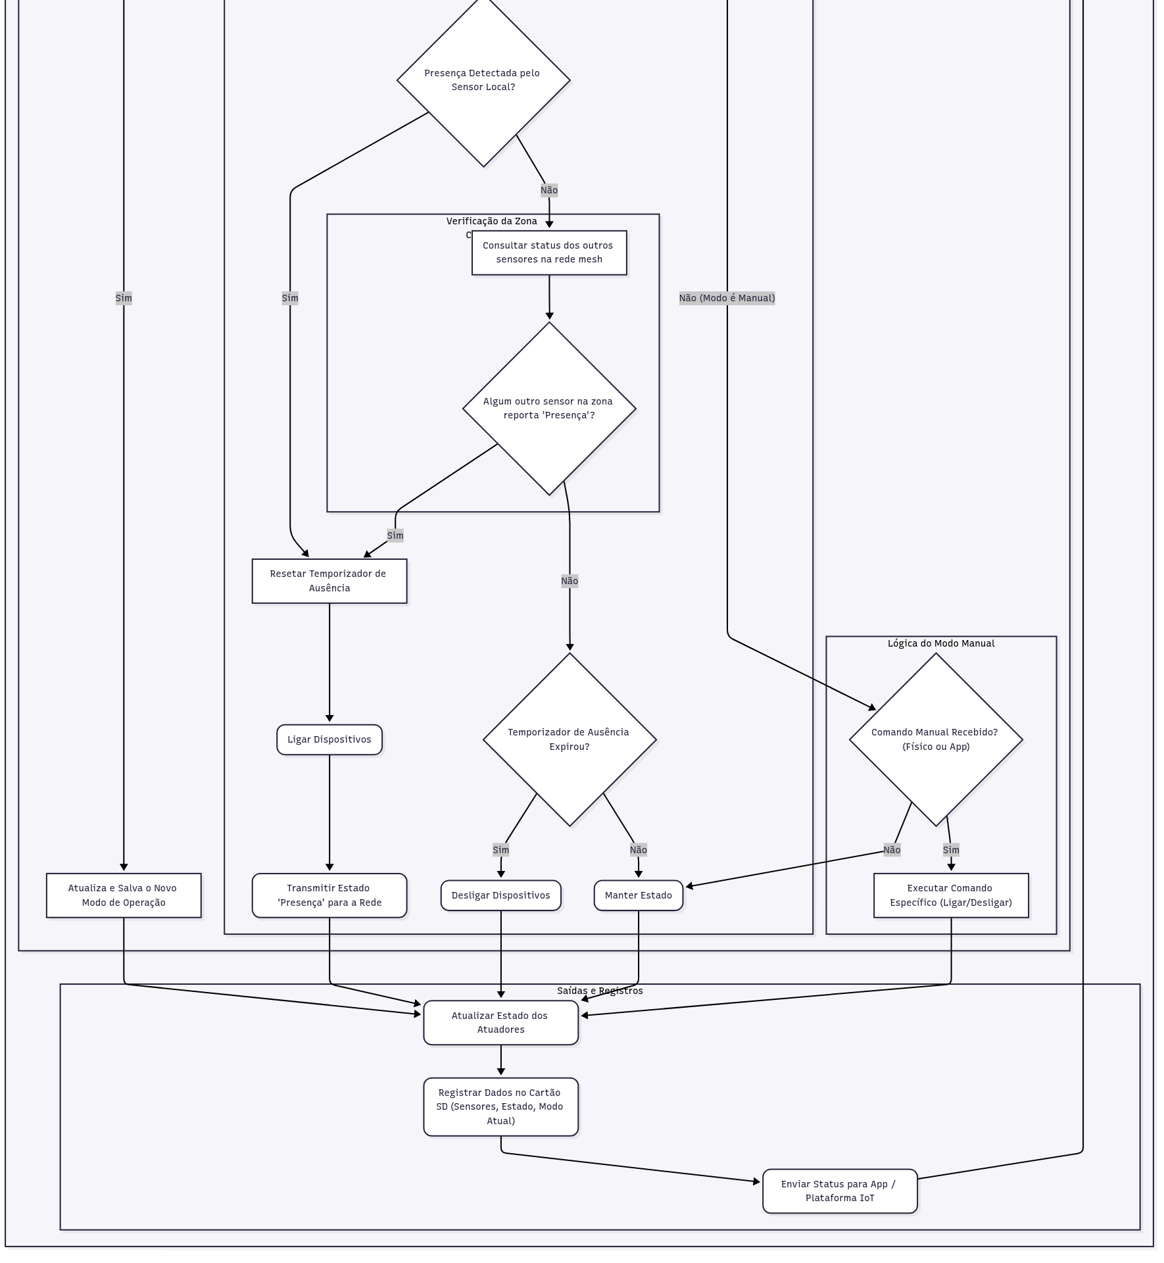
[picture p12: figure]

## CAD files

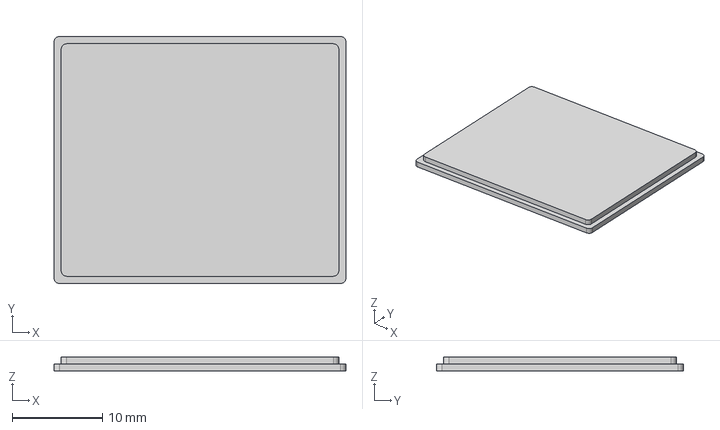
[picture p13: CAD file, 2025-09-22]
etapa_4/Part Studio 1/Part Studio 1 - Part 2.step
32.4 x 27.4 x 1.60 mm

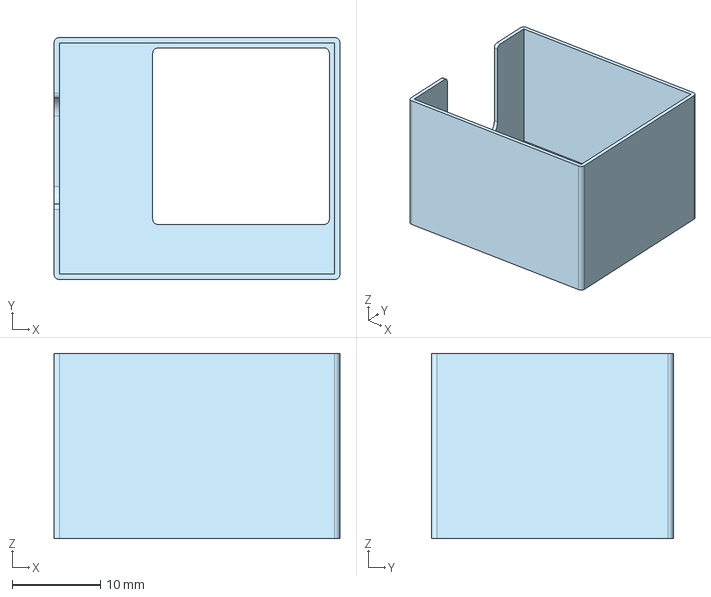
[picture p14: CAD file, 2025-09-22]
etapa_4/Part Studio 1/Part Studio 1 - Part 1.step
32.4 x 27.4 x 21.0 mm

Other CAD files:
etapa_4/Part Studio 1/Part Studio 1 - Part 1.3mf

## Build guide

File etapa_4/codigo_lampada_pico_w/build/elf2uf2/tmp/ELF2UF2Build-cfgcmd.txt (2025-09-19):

cmd='/home/pedro/.pico-sdk/cmake/v3.31.5/bin/cmake;-DCMAKE_MAKE_PROGRAM:FILEPATH=/home/pedro/.pico-sdk/ninja/v1.12.1/ninja;-GNinja;-S;<SOURCE_DIR><SOURCE_SUBDIR>;-B;<BINARY_DIR>'

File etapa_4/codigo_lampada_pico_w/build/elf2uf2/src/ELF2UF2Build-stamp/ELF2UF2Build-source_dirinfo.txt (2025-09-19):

# This is a generated file and its contents are an internal implementation detail.
# The download step will be re-executed if anything in this file changes.
# No other meaning or use of this file is supported.

method=source_dir
command=
source_dir=/home/pedro/.pico-sdk/sdk/1.5.1/tools/elf2uf2
work_dir=

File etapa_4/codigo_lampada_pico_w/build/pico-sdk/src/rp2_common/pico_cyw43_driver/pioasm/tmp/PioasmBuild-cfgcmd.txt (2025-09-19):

cmd='/home/pedro/.pico-sdk/cmake/v3.31.5/bin/cmake;-DCMAKE_MAKE_PROGRAM:FILEPATH=/home/pedro/.pico-sdk/ninja/v1.12.1/ninja;-GNinja;-C<TMP_DIR>/PioasmBuild-cache-$<CONFIG>.cmake;-S;<SOURCE_DIR><SOURCE_SUBDIR>;-B;<BINARY_DIR>'

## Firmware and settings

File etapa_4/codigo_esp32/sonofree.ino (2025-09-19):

#include <WiFi.h>
#include <PubSubClient.h>
#include <Preferences.h>

const char* SSID_WIFI = "SSID";
const char* SENHA_WIFI = "SENHA";

const char* SERVIDOR_MQTT = "IP_do_servidor_MQTT";
const uint16_t PORTA_MQTT = 1883;
const char* USUARIO_MQTT = "mqtt_user";
const char* SENHA_MQTT = "mqtt_password";

const char* TOPIC_CMD_MODO = "home/sensor/cmd";
const char* TOPIC_CMD_LUZ_PRES = "home/sensor/luz/cmd/presenca";
const char* TOPIC_CMD_LUZ_MAN = "home/sensor/luz/cmd/manual";
const char* TOPIC_CMD_LUZ_HORA = "home/sensor/luz/cmd/hora";
const char* TOPIC_PRESENCA_STATE = "home/sensor/presenca/state";
const char* TOPIC_TEMPO_SET = "home/sensor/presenca/tempo_s/set";
const char* TOPIC_TEMPO_STATE = "home/sensor/presenca/tempo_s/state";

const int PINO_PRESENCA = 4;
const int PINO_RELE = 1;
const bool RELE_ATIVO_ALTO = true;

enum Modo { MODO_PRESENCA, MODO_MANUAL, MODO_HORA };
volatile Modo modo_atual = MODO_PRESENCA;

String lamp_presenca = "OFF";
String lamp_manual = "OFF";
String lamp_hora = "OFF";
String estado_lampada = "OFF";

volatile bool estado_entrada_isr = false;
volatile bool flag_borda_subida = false;
volatile bool flag_borda_descida = false;

bool saida_virtual = false;
bool contando_tempo = false;
uint32_t instante_inicio = 0;

uint32_t tempo_ativo_seg = 10;
const uint32_t TEMPO_MIN = 1, TEMPO_MAX = 600;

volatile uint32_t ultimo_pulso_us = 0;
const uint32_t DEBOUNCE_US = 5000;
const uint32_t QUALIFICACAO_MS = 50;
bool aguardando_qualificacao = false;
uint32_t t_inicio_alta_ms = 0;

const unsigned long INTERVALO_PRINT_MS = 1000;
unsigned long t_ultimo_print = 0;

WiFiClient cliente_wifi;
PubSubClient mqtt(cliente_wifi);
Preferences preferencias;

const char* modo_para_str(Modo m) {
  switch (m) {
    case MODO_PRESENCA: return "Presença";
    case MODO_MANUAL: return "Manual";
    case MODO_HORA: return "Hora";
    default: return "Desconhecido";
  }
}

void aplicar_saida_lampada() {
  if (PINO_RELE < 0) return;
  bool ligar = (estado_lampada == "ON");
  if (!RELE_ATIVO_ALTO) ligar = !ligar;
  digitalWrite(PINO_RELE, ligar ? HIGH : LOW);
}

void publicar_tempo_state(bool retencao = true) {
  char buf[16];
  snprintf(buf, sizeof(buf), "%lu", (unsigned long)tempo_ativo_seg);
  mqtt.publish(TOPIC_TEMPO_STATE, buf, retencao);
  Serial.printf("[CFG] tempoAtivoSeg=%lus publicado em %s, retain=%s\n",
                (unsigned long)tempo_ativo_seg, TOPIC_TEMPO_STATE, retencao ? "true" : "false");
}

void tratar_tempo_set(const String& payload) {
  long v = payload.toInt();
  if (v <= 0 && payload != "0") {
    Serial.printf("[CFG] Payload invalido em %s: %s\n", TOPIC_TEMPO_SET, payload.c_str());
    return;
  }
  uint32_t novo = constrain((uint32_t)v, TEMPO_MIN, TEMPO_MAX);
  tempo_ativo_seg = novo;
  preferencias.putUInt("tempo_s", tempo_ativo_seg);
  publicar_tempo_state(true);
}

void IRAM_ATTR isr_presenca() {
  uint32_t agora_us = micros();
  if ((agora_us - ultimo_pulso_us) < DEBOUNCE_US) return;
  ultimo_pulso_us = agora_us;

  bool estado_atual = digitalRead(PINO_PRESENCA);
  static bool ultimo_estado = estado_atual;

  if (estado_atual && !ultimo_estado) flag_borda_subida = true;
  else if (!estado_atual && ultimo_estado) flag_borda_descida = true;

  estado_entrada_isr = estado_atual;
  ultimo_estado = estado_atual;
}

void ao_receber_mqtt(char* topico, byte* payload, unsigned int tamanho) {
  String msg; msg.reserve(tamanho);
  for (unsigned int i = 0; i < tamanho; i++) msg += (char)payload[i];
  msg.trim();

  if (strcmp(topico, TOPIC_CMD_MODO) == 0) {
    if (msg.equalsIgnoreCase("Presença") || msg.equalsIgnoreCase("Presenca")) modo_atual = MODO_PRESENCA;
    else if (msg.equalsIgnoreCase("Manual")) modo_atual = MODO_MANUAL;
    else if (msg.equalsIgnoreCase("Hora")) modo_atual = MODO_HORA;
    else { Serial.printf("[CMD] Payload invalido, modo: %s\n", msg.c_str()); return; }
    Serial.printf("[CMD] Modo alterado para %s\n", modo_para_str(modo_atual));
    if (modo_atual == MODO_PRESENCA) estado_lampada = lamp_presenca;
    if (modo_atual == MODO_MANUAL) estado_lampada = lamp_manual;
    if (modo_atual == MODO_HORA) estado_lampada = lamp_hora;
    aplicar_saida_lampada();
    return;
  }

  auto tratar_cmd_luz = [&](const char* topico_alvo, Modo modo, String& lamp_modo) -> bool {
    if (strcmp(topico, topico_alvo) != 0) return false;
    if (msg.equalsIgnoreCase("ON") || msg.equalsIgnoreCase("OFF")) {
      lamp_modo = msg;
      if (modo_atual == modo) {
        estado_lampada = msg;
        aplicar_saida_lampada();
        Serial.printf("[CMD] Luz %s aplicada no modo %s\n", estado_lampada.c_str(), modo_para_str(modo));
      } else {
        Serial.printf("[CMD] Luz %s registrada no modo %s (ignorada por enquanto)\n", lamp_modo.c_str(), modo_para_str(modo));
      }
    } else {
      Serial.printf("[CMD] Payload invalido, luz: %s\n", msg.c_str());
    }
    return true;
  };

  if (tratar_cmd_luz(TOPIC_CMD_LUZ_PRES, MODO_PRESENCA, lamp_presenca)) return;
  if (tratar_cmd_luz(TOPIC_CMD_LUZ_MAN, MODO_MANUAL, lamp_manual)) return;
  if (tratar_cmd_luz(TOPIC_CMD_LUZ_HORA, MODO_HORA, lamp_hora)) return;

  if (strcmp(topico, TOPIC_TEMPO_SET) == 0) {
    tratar_tempo_set(msg);
    return;
  }
}

void conectar_wifi() {
  WiFi.mode(WIFI_STA);
  WiFi.begin(SSID_WIFI, SENHA_WIFI);
  Serial.print("WiFi");
  int tentativas = 0;
  while (WiFi.status() != WL_CONNECTED) {
    delay(500); Serial.print(".");
    if (++tentativas > 120) { Serial.println("\nReiniciando por falta de WiFi"); ESP.restart(); }
  }
  Serial.print("\nIP: "); Serial.println(WiFi.localIP());
}

void conectar_mqtt() {
  mqtt.setServer(SERVIDOR_MQTT, PORTA_MQTT);
  mqtt.setBufferSize(256);
  mqtt.setCallback(ao_receber_mqtt);

  while (!mqtt.connected()) {
    String cid = "esp32_" + String((uint32_t)esp_random(), HEX);
    Serial.print("MQTT, tentando: "); Serial.println(cid);
    if (mqtt.connect(cid.c_str(), USUARIO_MQTT, SENHA_MQTT)) {
      mqtt.subscribe(TOPIC_CMD_MODO);
      mqtt.subscribe(TOPIC_CMD_LUZ_PRES);
      mqtt.subscribe(TOPIC_CMD_LUZ_MAN);
      mqtt.subscribe(TOPIC_CMD_LUZ_HORA);
      mqtt.subscribe(TOPIC_TEMPO_SET);
      Serial.println("MQTT conectado e inscrito");
      mqtt.publish(TOPIC_PRESENCA_STATE, saida_virtual ? "ON" : "OFF", true);
      publicar_tempo_state(true);
    } else {
      Serial.print("Falha MQTT rc="); Serial.println(mqtt.state());
      delay(3000);
    }
  }
}

void setup() {
  Serial.begin(115200);
  delay(100);

  preferencias.begin("cfg", false);
  tempo_ativo_seg = preferencias.getUInt("tempo_s", 10);

  pinMode(PINO_PRESENCA, INPUT_PULLDOWN);
  attachInterrupt(digitalPinToInterrupt(PINO_PRESENCA), isr_presenca, CHANGE);
  estado_entrada_isr = digitalRead(PINO_PRESENCA);

  if (PINO_RELE >= 0) {
    pinMode(PINO_RELE, OUTPUT);
    if (RELE_ATIVO_ALTO) digitalWrite(PINO_RELE, LOW);
    else digitalWrite(PINO_RELE, HIGH);
  }

  if (estado_entrada_isr) {
    aguardando_qualificacao = true;
    t_inicio_alta_ms = millis();
  }

  conectar_wifi();
  conectar_mqtt();

  Serial.println("Pronto.");
  Serial.printf("Inicial, Modo=%s, Lamp=%s, Presenca=%s, tempoAtivo=%lus\n",
                modo_para_str(modo_atual), estado_lampada.c_str(),
                saida_virtual ? "ON" : "OFF", (unsigned long)tempo_ativo_seg);
}

void loop() {
  if (WiFi.status() != WL_CONNECTED) conectar_wifi();
  if (!mqtt.connected()) conectar_mqtt();
  mqtt.loop();

  if (modo_atual == MODO_PRESENCA) {
    if (flag_borda_subida) {
      noInterrupts(); flag_borda_subida = false; interrupts();
      aguardando_qualificacao = true;
      t_inicio_alta_ms = millis();
      Serial.println("[PRESENCA] Borda subida, iniciando qualificacao de 50 ms");
    }

    if (flag_borda_descida) {
      noInterrupts(); flag_borda_descida = false; interrupts();
      if (aguardando_qualificacao) {
        aguardando_qualificacao = false;
        Serial.println("[PRESENCA] Borda descida durante qualificacao, cancelado");
      }
      contando_tempo = true;
      instante_inicio = millis();
      Serial.println("[PRESENCA] Borda descida, iniciando contagem para OFF");
    }

    if (aguardando_qualificacao) {
      if (!estado_entrada_isr) {
        aguardando_qualificacao = false;
      } else if ((millis() - t_inicio_alta_ms) >= QUALIFICACAO_MS && !saida_virtual) {
        saida_virtual = true;
        aguardando_qualificacao = false;
        contando_tempo = false;
        bool ok = mqtt.publish(TOPIC_PRESENCA_STATE, "ON", true);
        Serial.printf("[PRESENCA] Qualificacao OK, %lums -> ON, pub=%s\n",
                      (unsigned long)QUALIFICACAO_MS, ok ? "ok" : "falha");
        lamp_presenca = "ON";
        estado_lampada = "ON";
        aplicar_saida_lampada();
      }
    }

    if (contando_tempo && !estado_entrada_isr) {
      uint32_t decorrido = (millis() - instante_inicio) / 1000;
      if (decorrido >= tempo_ativo_seg) {
        saida_virtual = false;
        contando_tempo = false;
        bool ok = mqtt.publish(TOPIC_PRESENCA_STATE, "OFF", true);
        Serial.printf("[PRESENCA] Tempo expirou, %lus -> OFF, pub=%s\n",
                      (unsigned long)tempo_ativo_seg, ok ? "ok" : "falha");
        lamp_presenca = "OFF";
        estado_lampada = "OFF";
        aplicar_saida_lampada();
      }
    }

    if (contando_tempo && estado_entrada_isr) {
      contando_tempo = false;
      aguardando_qualificacao = true;
      t_inicio_alta_ms = millis();
      Serial.println("[PRESENCA] Retorno a HIGH durante contagem, recomecando qualificacao");
    }
  }

  unsigned long agora = millis();
  if (agora - t_ultimo_print >= INTERVALO_PRINT_MS) {
    t_ultimo_print = agora;
    Serial.printf("[STATUS] Modo=%s, Lamp=%s, Presenca=%s, tempoAtivo=%lus | CmdPres=%s, CmdMan=%s, CmdHora=%s\n",
                  modo_para_str(modo_atual), estado_lampada.c_str(),
                  saida_virtual ? "ON" : "OFF", (unsigned long)tempo_ativo_seg,
                  lamp_presenca.c_str(), lamp_manual.c_str(), lamp_hora.c_str());
  }
}

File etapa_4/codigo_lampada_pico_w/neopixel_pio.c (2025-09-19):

#include "pico/stdlib.h"
#include "hardware/pio.h"
#include "hardware/clocks.h"
#include "ws2818b.pio.h"

#define PIN_LED        7
#define QTD_LEDS       25
#define PIN_ENTRADA    18
#define DEBOUNCE_MS    10

static inline uint8_t inverter_bits8(uint8_t v) {
    v = (uint8_t)((v >> 1) & 0x55) | (uint8_t)((v & 0x55) << 1);
    v = (uint8_t)((v >> 2) & 0x33) | (uint8_t)((v & 0x33) << 2);
    v = (uint8_t)((v >> 4) & 0x0F) | (uint8_t)((v & 0x0F) << 4);
    return v;
}

static void escrever_cor_solida(PIO pio, uint maquina, uint8_t r, uint8_t g, uint8_t b) {
    uint8_t G = inverter_bits8(g), R = inverter_bits8(r), B = inverter_bits8(b);
    for (uint i = 0; i < QTD_LEDS; ++i) {
        pio_sm_put_blocking(pio, maquina, G);
        pio_sm_put_blocking(pio, maquina, R);
        pio_sm_put_blocking(pio, maquina, B);
    }
    sleep_us(100);
}

int main() {
    stdio_init_all();

    gpio_init(PIN_ENTRADA);
    gpio_set_dir(PIN_ENTRADA, false);
    gpio_pull_down(PIN_ENTRADA);

    PIO pio = pio0;
    uint deslocamento = pio_add_program(pio, &ws2818b_program);
    int indice_sm = pio_claim_unused_sm(pio, false);
    if (indice_sm < 0) {
        pio = pio1;
        deslocamento = pio_add_program(pio, &ws2818b_program);
        indice_sm = pio_claim_unused_sm(pio, true);
    }
    uint maquina = (uint)indice_sm;

    ws2818b_program_init(pio, maquina, deslocamento, PIN_LED, 800000.f);

    bool ultimo_ligado = false;
    escrever_cor_solida(pio, maquina, 0, 0, 0);

    while (true) {
        bool leitura1 = gpio_get(PIN_ENTRADA);
        sleep_ms(DEBOUNCE_MS);
        bool leitura2 = gpio_get(PIN_ENTRADA);
        bool ligado = leitura1 && leitura2;

        if (ligado != ultimo_ligado) {
            ultimo_ligado = ligado;
            if (ligado) {
                escrever_cor_solida(pio, maquina, 255, 255, 255);
            } else {
                escrever_cor_solida(pio, maquina, 0, 0, 0);
            }
        }
        sleep_ms(5);
    }
}
